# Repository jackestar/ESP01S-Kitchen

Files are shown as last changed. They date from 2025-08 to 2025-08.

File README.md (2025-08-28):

<div align="center">
<h3>ESP01S controlled for a Resistive Element (Kitchen)</h3>
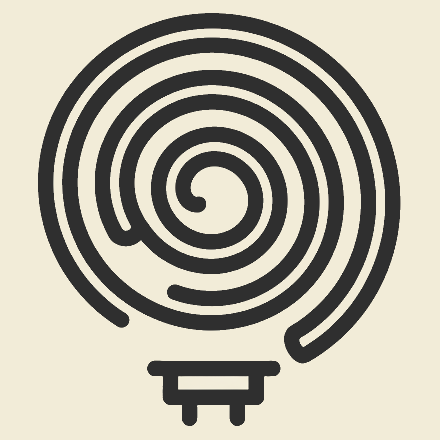
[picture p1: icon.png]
icon

</div>

---

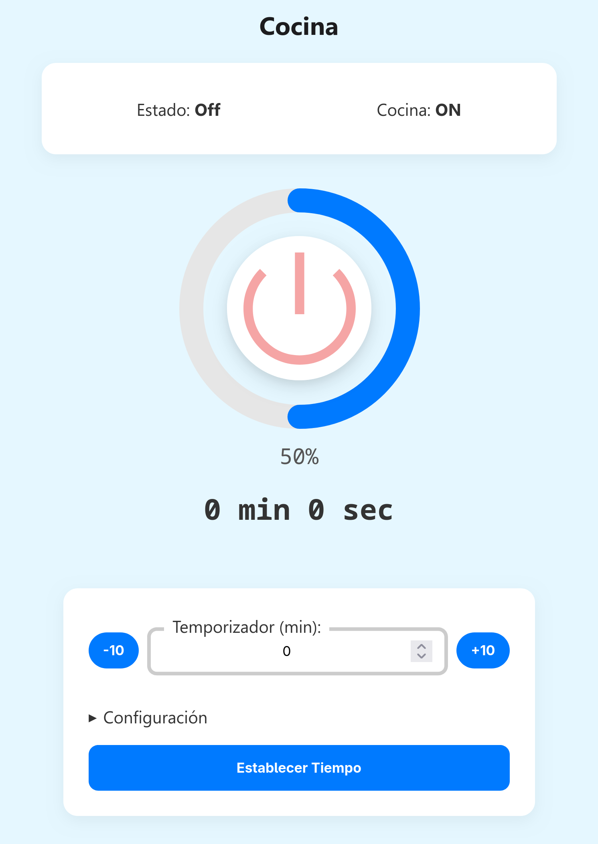
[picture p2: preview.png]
Preview


## Goal

Controlling a resistive AC heating element using an SSR (Solid State Relay) controlled by a ESP01 (or ESP01S, ESP8266 based board), using the ESP8266 RTOS SDK.

* Push-button On/Off :heavy_check_mark:
* App Control (On/Off, Timer, Dimmer) :heavy_check_mark:
* OTA Update :x:
* Translations :x:
* CI/CD (Github Actions) :heavy_check_mark:

## Build

> [!NOTE]
> The main difference between the ESP01 and the ESP01S is the flash memory size, the Espressif SDK allows a minimum of 1MB so it verifies that the compiled file fits in the flash memory (~450kB ~330Kb compressed).

* Install the [ESP8266 RTOS SDK](https://github.com/espressif/ESP8266_RTOS_SDK) and configure it.
* Clone this repo

```bash
git clone https://github.com/jackestar/ESP01S-Kitchen.git --depth 2
```

* set the environment `export IDF_PATH=[your ESP8266 SDK path]` and `. $IDF_PATH/export.sh`

* make and flash

```
make flash
```

## Board and Schematics

[Articulo del Esquemático](https://jackestar.netlify.app/Blog/Kicad/ESP01S-Kitchen-Driver.html)

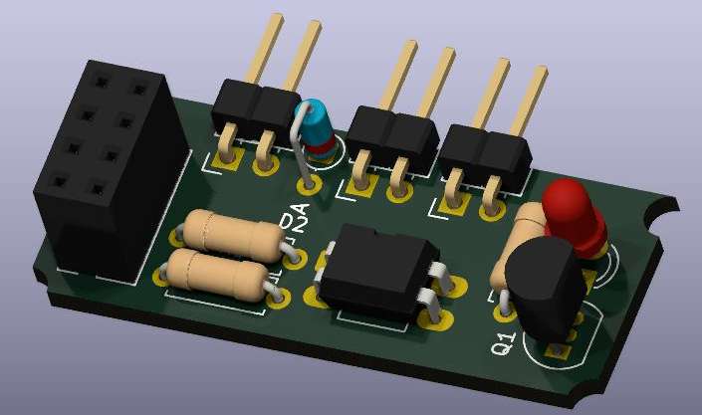
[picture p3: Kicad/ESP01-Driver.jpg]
Driver


[Kicad Project](Kicad)

# License

**This Repo** - MIT License

**ESP8266 RTOS SDK** - Apache 2.0

**Material Symbols / Material Icons** - Apache 2.0

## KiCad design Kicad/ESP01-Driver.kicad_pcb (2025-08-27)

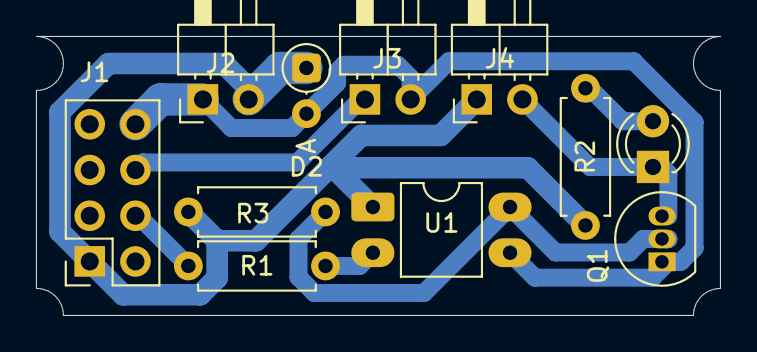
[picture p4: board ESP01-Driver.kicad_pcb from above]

Board: 2 copper layers, 38.0 x 15.5 mm, 11 parts (0 on the bottom side), 8 nets.

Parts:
D1: LED; LED_D3.0mm
D2: 3v6; D_DO-35_SOD27_P2.54mm_Vertical_AnodeUp
J1: ESP01S; PinSocket_2x04_P2.54mm_Vertical
J2: Supply; PinHeader_1x02_P2.54mm_Horizontal
J3: Push Button; PinHeader_1x02_P2.54mm_Horizontal
J4: Relay; PinHeader_1x02_P2.54mm_Horizontal
Q1: 2N2222A; TO-92_Inline
R1: 100; R_Axial_DIN0207_L6.3mm_D2.5mm_P7.62mm_Horizontal
R2: 220; R_Axial_DIN0207_L6.3mm_D2.5mm_P7.62mm_Horizontal
R3: 3.3k; R_Axial_DIN0207_L6.3mm_D2.5mm_P7.62mm_Horizontal
U1: PC123; DIP-4_W7.62mm_LongPads

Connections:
+3V3: D2.1 (K), J1.1, J2.2, J4.1, R2.1, R3.1, U1.1
GND: D2.2 (A), J1.8, J2.1, J3.2, Q1.1 (E), U1.3
IO0: J1.4, R1.1
IO2: J1.6, J3.1
unnamed: D1.2 (A), R2.2
unnamed: D1.1 (K), J4.2, Q1.3 (C)
unnamed: Q1.2 (B), R3.2, U1.4
unnamed: R1.2, U1.2

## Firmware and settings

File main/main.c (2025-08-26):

#include <stdio.h>
#include <string.h>
#include "freertos/FreeRTOS.h"
#include "freertos/task.h"
#include "freertos/queue.h"
#include "freertos/semphr.h"
#include "esp_system.h"
#include "esp_spi_flash.h"
#include "driver/gpio.h"
#include "esp_wifi.h"
#include "esp_event.h"
#include "nvs_flash.h"
#include "esp_http_server.h"
#include "esp_log.h"    // added to allow disabling logs

#define SWITCH_GPIO 2  // GPIO2 as input (must be HIGH at boot)
#define OUTPUT_GPIO 0  // GPIO0 as output for the heating element
#define ACTIVE_GPIO 3  // RX as an indicator LED
#define ACTIVE2_GPIO 1 // TX as an indicator LED

#define DEBOUNCE_MS 250
#define MINUTE 60000 // Milliseconds in a minute

// --- Global State and Configuration ---
static volatile bool system_on = false;
static volatile bool output_state = false; // Represents the physical output pin state
static volatile int initial_on_time = 2;   // minutes
static volatile int pwm_period = 1;        // minutes (0 = disabled)
static volatile int pwm_duty = 100;        // percent
static volatile int timer_minutes = 0;     // minutes (0 = disabled)
static volatile int time_left_seconds = 0; // Time left for the timer in seconds

// --- RTOS Handles ---
static QueueHandle_t gpio_evt_queue = NULL;
static SemaphoreHandle_t state_mutex = NULL; // Mutex for protecting shared variables
static TaskHandle_t heater_task_handle = NULL;
static TaskHandle_t timer_task_handle = NULL;

extern const char index_html_start[] asm("_binary_index_html_start");
extern const char index_html_end[] asm("_binary_index_html_end");

#if __has_include("credentials.h")
#include "credentials.h"
#endif

#ifndef CREDENTIALS_H
#define WIFI_SSID "default_ssid"
#define WIFI_PASS "default_pass"
#endif

// Forward declarations
void heater_control_task(void* arg);
void timer_task(void* arg);

void wifi_init_sta(void);
void start_webserver(void);

/**
 * @brief A responsive delay that checks system status frequently.
 * @param ms The total duration to delay in milliseconds.
 * @return true if the delay completed fully, false if it was aborted by the system turning off.
 */
static bool responsive_delay_ms(uint32_t ms) {
    TickType_t start_ticks = xTaskGetTickCount();
    // Use a 64-bit integer to prevent overflow with long durations
    uint64_t duration_ticks = (uint64_t)ms / portTICK_PERIOD_MS;

    while ((xTaskGetTickCount() - start_ticks) < duration_ticks) {
        // Check system status frequently (e.g., every 100ms)
        vTaskDelay(pdMS_TO_TICKS(100));

        xSemaphoreTake(state_mutex, portMAX_DELAY);
        bool is_on = system_on;
        xSemaphoreGive(state_mutex);

        // If system was turned off externally, abort the delay
        if (!is_on) {
            return false;
        }
    }
    return true; // Delay completed without interruption
}

static void IRAM_ATTR gpio_isr_handler(void* arg) {
    uint32_t gpio_num = (uint32_t)arg;
    xQueueSendFromISR(gpio_evt_queue, &gpio_num, NULL);
}

void switch_task(void* arg) {
    uint32_t io_num;
    TickType_t last_interrupt_time = 0;

    while (1) {
        if (xQueueReceive(gpio_evt_queue, &io_num, portMAX_DELAY)) {
            TickType_t current_time = xTaskGetTickCount();
            if ((current_time - last_interrupt_time) * portTICK_PERIOD_MS > DEBOUNCE_MS) {
                // Only toggle on falling edge (button press)
                if (gpio_get_level(SWITCH_GPIO) == 0) {
                    if (xSemaphoreTake(state_mutex, portMAX_DELAY) == pdTRUE) {
                        system_on = !system_on;
                        // If turning off, also cancel the timer
                        if (!system_on) {
                            timer_minutes = 0;
                            time_left_seconds = 0;
                        }
                        xSemaphoreGive(state_mutex);
                    }
                }
                last_interrupt_time = current_time;
            }
        }
    }
}

// --- Web Server ---
const char* get_status_string() {
    if (!system_on)
        return "Off";
    if (timer_minutes > 0 && pwm_period > 0)
        return "On - Temporizador & Regulado";
    if (timer_minutes > 0)
        return "On - Temporizador";
    if (pwm_period > 0)
        return "On - Regulado";
    return "On";
}

// A helper function to replace a string in a buffer.
// Returns the new length of the buffer.
static int replace_string(char* buf, int buf_size, const char* find, const char* replace) {
    char* pos = strstr(buf, find);
    if (!pos)
        return strlen(buf); // Substring not found

    int find_len = strlen(find);
    int replace_len = strlen(replace);
    int tail_len = strlen(pos + find_len);

    // Check if the new string will fit
    if (strlen(buf) - find_len + replace_len >= buf_size)
        return strlen(buf); // Not enough space, cannot replace.

    // Move the tail end of the buffer to make room
    memmove(pos + replace_len, pos + find_len, tail_len + 1); // /NULL
    // Copy the replacement string into the gap
    memcpy(pos, replace, replace_len);

    return strlen(buf);
}

esp_err_t ui_get_handler(httpd_req_t* req) {
    // Calculate the size of the embedded HTML file.
    const size_t html_size = (index_html_end - index_html_start);
    // Allocate a buffer large enough for the HTML plus some room for replacements.
    char* resp_buf = malloc(html_size + 512);
    if (!resp_buf) {
        httpd_resp_send_500(req);
        return ESP_FAIL;
    }

    // Copy the embedded HTML template into the buffer.
    memcpy(resp_buf, index_html_start, html_size);
    resp_buf[html_size] = '\0'; // Null-terminate the string.

    // --- Replace Placeholders with Dynamic Data ---
    xSemaphoreTake(state_mutex, portMAX_DELAY);

    // Prepare replacement strings
    char output_state_str[5];
    snprintf(output_state_str, sizeof(output_state_str), "%s", output_state ? "ON" : "OFF");

    char time_left_str[30];
    snprintf(time_left_str, sizeof(time_left_str), "%d min %d sec", time_left_seconds / 60, time_left_seconds % 60);

    char initial_on_str[5], pwm_period_str[5], pwm_duty_str[5], timer_mins_str[5];
    snprintf(initial_on_str, sizeof(initial_on_str), "%d", initial_on_time);
    snprintf(pwm_period_str, sizeof(pwm_period_str), "%d", pwm_period);
    snprintf(pwm_duty_str, sizeof(pwm_duty_str), "%d", pwm_duty);
    snprintf(timer_mins_str, sizeof(timer_mins_str), "%d", timer_minutes);

    const char* status_str = get_status_string(); // Keep this helper for the status text

    xSemaphoreGive(state_mutex);

    replace_string(resp_buf, html_size + 512, "%%STATUS%%", status_str);
    replace_string(resp_buf, html_size + 512, "%%OUTPUT_STATE%%", output_state_str);
    replace_string(resp_buf, html_size + 512, "%%TIME_LEFT%%", time_left_str);
    replace_string(resp_buf, html_size + 512, "%%INITIAL_ON%%", initial_on_str);
    replace_string(resp_buf, html_size + 512, "%%PWM_PERIOD%%", pwm_period_str);
    replace_string(resp_buf, html_size + 512, "%%PWM_DUTY%%", pwm_duty_str);
    replace_string(resp_buf, html_size + 512, "%%TIMER_MINS%%", timer_mins_str);

    // Send the modified buffer as the response.
    httpd_resp_send(req, resp_buf, strlen(resp_buf));

    // Clean up the allocated memory.
    free(resp_buf);

    return ESP_OK;
}

esp_err_t ui_post_handler(httpd_req_t* req) {
    char buf[256];
    int ret = httpd_req_recv(req, buf, sizeof(buf) - 1);
    if (ret > 0) {
        buf[ret] = '\0';
        xSemaphoreTake(state_mutex, portMAX_DELAY);
        if (strstr(buf, "toggle=1")) {
            system_on = !system_on;
            if (!system_on) { // Off - end timer
                timer_minutes = 0;
                time_left_seconds = 0;
            }
        }
        char val_buf[10];
        if (httpd_query_key_value(buf, "initial_on_time", val_buf, sizeof(val_buf)) == ESP_OK)
            initial_on_time = atoi(val_buf);
        if (httpd_query_key_value(buf, "pwm_period", val_buf, sizeof(val_buf)) == ESP_OK)
            pwm_period = atoi(val_buf);
        if (httpd_query_key_value(buf, "pwm_duty", val_buf, sizeof(val_buf)) == ESP_OK)
            pwm_duty = atoi(val_buf);
        if (httpd_query_key_value(buf, "timer_minutes", val_buf, sizeof(val_buf)) == ESP_OK)
            timer_minutes = atoi(val_buf);
        xSemaphoreGive(state_mutex);
    }
    httpd_resp_set_status(req, "303 See Other");
    httpd_resp_set_hdr(req, "Location", "/");
    httpd_resp_send(req, NULL, 0);
    return ESP_OK;
}

esp_err_t state_get_handler(httpd_req_t* req) {
    char json_response[256];

    xSemaphoreTake(state_mutex, portMAX_DELAY);
    snprintf(json_response, sizeof(json_response),
        "{\"status\":\"%s\",\"output_state\":\"%s\",\"time_left\":\"%d min %d sec\",\"initial_on_time\":%d,\"pwm_period\":%d,\"pwm_duty\":%d,\"timer_minutes\":%d}",
        get_status_string(),
        output_state ? "ON" : "OFF",
        time_left_seconds / 60, time_left_seconds % 60,
        initial_on_time, pwm_period, pwm_duty, timer_minutes);
    xSemaphoreGive(state_mutex);

    httpd_resp_set_type(req, "application/json");
    httpd_resp_send(req, json_response, strlen(json_response));

    return ESP_OK;
}

// --- Control Tasks ---

void heater_control_task(void* arg) {
    bool was_on = false;
    bool initial_period_has_run = false;

    while (1) {
        xSemaphoreTake(state_mutex, portMAX_DELAY);
        bool is_on = system_on;

        // On state transition from OFF to ON, reset the initial run flag.
        if (is_on && !was_on)
            initial_period_has_run = false;

        was_on = is_on;

        // If system is OFF, all hardware is off and wait.
        if (!is_on) {
            if (output_state) {
                gpio_set_level(OUTPUT_GPIO, 0);
                gpio_set_level(ACTIVE_GPIO, 0);
                gpio_set_level(ACTIVE2_GPIO, 0);
                output_state = false;
            }
            xSemaphoreGive(state_mutex);
            vTaskDelay(pdMS_TO_TICKS(100)); // Short delay while idle
            continue;
        }

        // --- System is ON ---
        gpio_set_level(ACTIVE_GPIO, 1);
        gpio_set_level(ACTIVE2_GPIO, 1);

        int local_initial_on_time = initial_on_time;
        int local_pwm_period = pwm_period;
        int local_pwm_duty = pwm_duty;
        xSemaphoreGive(state_mutex);

        // --- Priority 1: Initial ON Period ----
        if (local_initial_on_time > 0 && !initial_period_has_run) {
            gpio_set_level(OUTPUT_GPIO, 1);
            xSemaphoreTake(state_mutex, portMAX_DELAY);
            output_state = true;
            xSemaphoreGive(state_mutex);

            // Use the responsive delay. If it's aborted, restart the loop.
            if (!responsive_delay_ms((uint32_t)local_initial_on_time * MINUTE)) {
                continue;
            }
            initial_period_has_run = true;
            continue; // Re-evaluate state immediately after this period
        }

        // --- Priority 2: PWM or Steady-ON ----
        if (local_pwm_period > 0) {
            if (local_pwm_duty >= 100) {
                gpio_set_level(OUTPUT_GPIO, 1);
                xSemaphoreTake(state_mutex, portMAX_DELAY);
                output_state = true;
                xSemaphoreGive(state_mutex);
                if (!responsive_delay_ms(1000))
                    continue; // Check state every second
            } else if (local_pwm_duty <= 0) {
                gpio_set_level(OUTPUT_GPIO, 0);
                xSemaphoreTake(state_mutex, portMAX_DELAY);
                output_state = false;
                xSemaphoreGive(state_mutex);
                if (!responsive_delay_ms(1000))
                    continue; // Check state every second
            } else {
                uint32_t period_ms = (uint32_t)local_pwm_period * MINUTE;
                uint32_t on_time_ms = (period_ms * local_pwm_duty) / 100;

                gpio_set_level(OUTPUT_GPIO, 1);
                xSemaphoreTake(state_mutex, portMAX_DELAY);
                output_state = true;
                xSemaphoreGive(state_mutex);
                if (!responsive_delay_ms(on_time_ms))
                    continue;

                gpio_set_level(OUTPUT_GPIO, 0);
                xSemaphoreTake(state_mutex, portMAX_DELAY);
                output_state = false;
                xSemaphoreGive(state_mutex);
                if (!responsive_delay_ms(period_ms - on_time_ms))
                    continue;
            }
        } else { // No PWM, steady ON
            gpio_set_level(OUTPUT_GPIO, 1);
            xSemaphoreTake(state_mutex, portMAX_DELAY);
            output_state = true;
            xSemaphoreGive(state_mutex);
            if (!responsive_delay_ms(500))
                continue; // Yield periodically
        }
    }
}

void timer_task(void* arg) {
    int local_timer_minutes = 0;
    bool timer_was_active = false;

    while (1) {
        if (xSemaphoreTake(state_mutex, portMAX_DELAY) == pdTRUE) {
            local_timer_minutes = timer_minutes;

            if (system_on && local_timer_minutes > 0 && !timer_was_active) {
                // Timer was just started
                time_left_seconds = local_timer_minutes * 60;
                timer_was_active = true;
            } else if (!system_on || local_timer_minutes == 0) {
                // Reset timer if system is off or timer is set to 0
                time_left_seconds = 0;
                timer_was_active = false;
            }

            if (timer_was_active && time_left_seconds > 0) {
                time_left_seconds--;
                if (time_left_seconds <= 0) {
                    system_on = false; // Timer expired, turn system off
                    timer_minutes = 0; // Clear the timer setting
                    timer_was_active = false;
                }
            }
            xSemaphoreGive(state_mutex);
        }
        vTaskDelay(pdMS_TO_TICKS(1000)); // Check every second
    }
}

void app_main() {
    esp_err_t ret = nvs_flash_init();
    if (ret == ESP_ERR_NVS_NO_FREE_PAGES || ret == ESP_ERR_NVS_NEW_VERSION_FOUND) {
        nvs_flash_erase();
        nvs_flash_init();
    }

    // Disable all esp logging to avoid UART/console prints
    esp_log_level_set("*", ESP_LOG_NONE);

    fsync(fileno(stdout));
    fsync(fileno(stderr));
    setvbuf(stdout, NULL, _IONBF, 0);

    state_mutex = xSemaphoreCreateMutex();

    gpio_set_direction(OUTPUT_GPIO, GPIO_MODE_OUTPUT);
    gpio_set_level(OUTPUT_GPIO, 0);
    gpio_set_direction(ACTIVE_GPIO, GPIO_MODE_OUTPUT);
    gpio_set_level(ACTIVE_GPIO, 0);
    gpio_set_direction(ACTIVE2_GPIO, GPIO_MODE_OUTPUT);
    gpio_set_level(ACTIVE2_GPIO, 0);

    gpio_set_direction(SWITCH_GPIO, GPIO_MODE_INPUT);
    gpio_set_pull_mode(SWITCH_GPIO, GPIO_PULLUP_ONLY);

    gpio_evt_queue = xQueueCreate(10, sizeof(uint32_t));
    gpio_install_isr_service(0);
    gpio_set_intr_type(SWITCH_GPIO, GPIO_INTR_NEGEDGE);
    gpio_isr_handler_add(SWITCH_GPIO, gpio_isr_handler, (void*)SWITCH_GPIO);

    wifi_init_sta();
    start_webserver();

    xTaskCreate(switch_task, "switch_task", 2048, NULL, 10, NULL);
    xTaskCreate(heater_control_task, "heater_control_task", 2048, NULL, 5, &heater_task_handle);
    xTaskCreate(timer_task, "timer_task", 2048, NULL, 4, &timer_task_handle);
}

static void wifi_event_handler(void* arg, esp_event_base_t event_base, int32_t event_id, void* event_data) {
    if (event_base == WIFI_EVENT && event_id == WIFI_EVENT_STA_START) {
        esp_wifi_connect();
    } else if (event_base == WIFI_EVENT && event_id == WIFI_EVENT_STA_DISCONNECTED) {
        esp_wifi_connect();
    }
}

void start_webserver(void) {
    httpd_handle_t server = NULL;
    httpd_config_t config = HTTPD_DEFAULT_CONFIG();
    config.stack_size = 8192;
    httpd_start(&server, &config);

    httpd_uri_t ui_get = { .uri = "/", .method = HTTP_GET, .handler = ui_get_handler, .user_ctx = NULL };
    httpd_uri_t ui_post = { .uri = "/", .method = HTTP_POST, .handler = ui_post_handler, .user_ctx = NULL };
    httpd_uri_t state_get = { .uri = "/state", .method = HTTP_GET, .handler = state_get_handler, .user_ctx = NULL };

    httpd_register_uri_handler(server, &ui_get);
    httpd_register_uri_handler(server, &ui_post);
    httpd_register_uri_handler(server, &state_get);
}

void wifi_init_sta(void) {
    tcpip_adapter_init();

    // Call functions but do not use ESP_ERROR_CHECK (no console output).
    // Store and ignore return codes to avoid printing.
    esp_event_loop_create_default();

    esp_event_handler_register(WIFI_EVENT, ESP_EVENT_ANY_ID, &wifi_event_handler, NULL);

    esp_event_handler_register(IP_EVENT, IP_EVENT_STA_GOT_IP, &wifi_event_handler, NULL);

    wifi_init_config_t cfg = WIFI_INIT_CONFIG_DEFAULT();
    esp_wifi_init(&cfg);

    esp_wifi_set_mode(WIFI_MODE_STA);

    wifi_config_t wifi_config = {
        .sta = {
            .ssid = WIFI_SSID,
            .password = WIFI_PASS,
        },
    };

    esp_wifi_set_config(ESP_IF_WIFI_STA, &wifi_config);

    esp_wifi_start();
}

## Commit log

2025-08-26 Update UI/UX Add +-10 min Button Upd each 1s fix Upd Readme Add Licence Upd sdkconfig (nothing to do)
    [main.c]
2025-08-26 skdconfig with UART (for no pathed version)
2025-08-27 Add Kicad Board Schematics Upd Preview Add Build Readme Upd Github action CI
    [ESP01-Driver.kicad_pcb, ESP01-Driver.kicad_sch]
